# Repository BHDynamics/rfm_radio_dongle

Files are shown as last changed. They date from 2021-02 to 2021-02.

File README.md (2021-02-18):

# DynaLoRa USB Radio Dongle
DynaLoRa USB Radio is a low cost, CircuitPython and Arduino compatible USB radio dongle.

This plaform is equipped with an ATSAMD21 micrcontroller, plus a HopeRF radio module. By default we chose the RFM96W, a LoRa 868 - 915 MHz module based on Semtech's SX1276. You can use an RFM95W for 433 MHz, or an RFM69HCW for generic non-LoRa Sub-GHz radios since they are pin compatible.

Hardware in this repository is licenced under **CERN OHL v1.2**.

## Technical details

- ATSAMD21E18 48 MHz Cortex-M0+ processor with 256 KB flash + 32 KB RAM, compatible with CircuitPython and Arduino
- 32 Mbit SPI flash for storing CircuitPython code and libraries
- High performance HopeRF radio module. You can choose between LoRa (RFM96W, RFM95W) or regular Sub-GHz (RFM69HCW).
- User-controllable WS2812B addressable RGB LED
- Regular user LED
- 3V3 @ 1A power through a DC/DC buck regulator from USB
- MicroSD Card slot
- GPIO header exposing SWD interface, a full SERCOM (enabling external SPI/I2C/UART peripherals) and a DAC for prototyping
- This version comes with an USB-A plug. It should be easy enough to modify the design to offer other options (such as USB-C).

## Documentation

Available in our [Wiki](https://github.com/BHDynamics/rfm_radio_dongle/wiki).

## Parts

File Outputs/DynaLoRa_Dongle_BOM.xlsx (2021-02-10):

Reference(s) | Qty | Part Number | Value | Comments
C1, C2 | 2 |  | 10nF | 10 nF 0402
C3, C4 | 2 |  | 100nF | 100 nF 0402
C5 | 1 |  | 1uF | 1 uF 0603
C6, C9, C10 | 3 |  | 22uF | 22 uF 0603 X5R or X7R
D1 | 1 | WS2812B-MINI | WS2812B-MINI | Addressable LED RGB
D2 | 1 |  | LED_Small | 0805 Red LED
D3 | 1 |  | LED_Small | 0805 Blue LED
J1 | 1 | DO NOT PLACE | Conn_01x07 | Pin header 1x07 2.54 mm SMD horizontal
J2 | 1 | U217-041N-4BV81 | USB_A | USB-A 2.0 Plug
J3 | 1 | PCB.RPSMAFRA.HT* | Conn_Coaxial | SMA THT female connector with pin.
J4 | 1 | TF-102-18 | Micro_SD_Card | MicroSD card slot
L2 | 1 | L1210R2R2MDWIT | 2.2uH | 1210 2.2uH 2A Inductor
R1, R2, R6, R7 | 4 |  | 100k | 100k 0402 1%
R3, R4, R5 | 3 |  | 510R | 510 ohm 0402 1%
R8 | 1 |  | 22k | 22.1k 0402 1%
SW1, SW2 | 2 | B3U-3000P | SW_Push | SMD push button
U1 | 1 | GD25Q32CNIGR | GD25Q32 | 32 Mbit QSPI flash memory
U2 | 1 | ATSAMD21E18A-AUT | ATSAMD21E18A | Cortex-M0 MCU
U3 | 1 | RFM95W | RFM9X | 868-915 MHz LoRa Radio module
U4 | 1 | SY8088AAC | SY8088 | DC/DC Buck converter

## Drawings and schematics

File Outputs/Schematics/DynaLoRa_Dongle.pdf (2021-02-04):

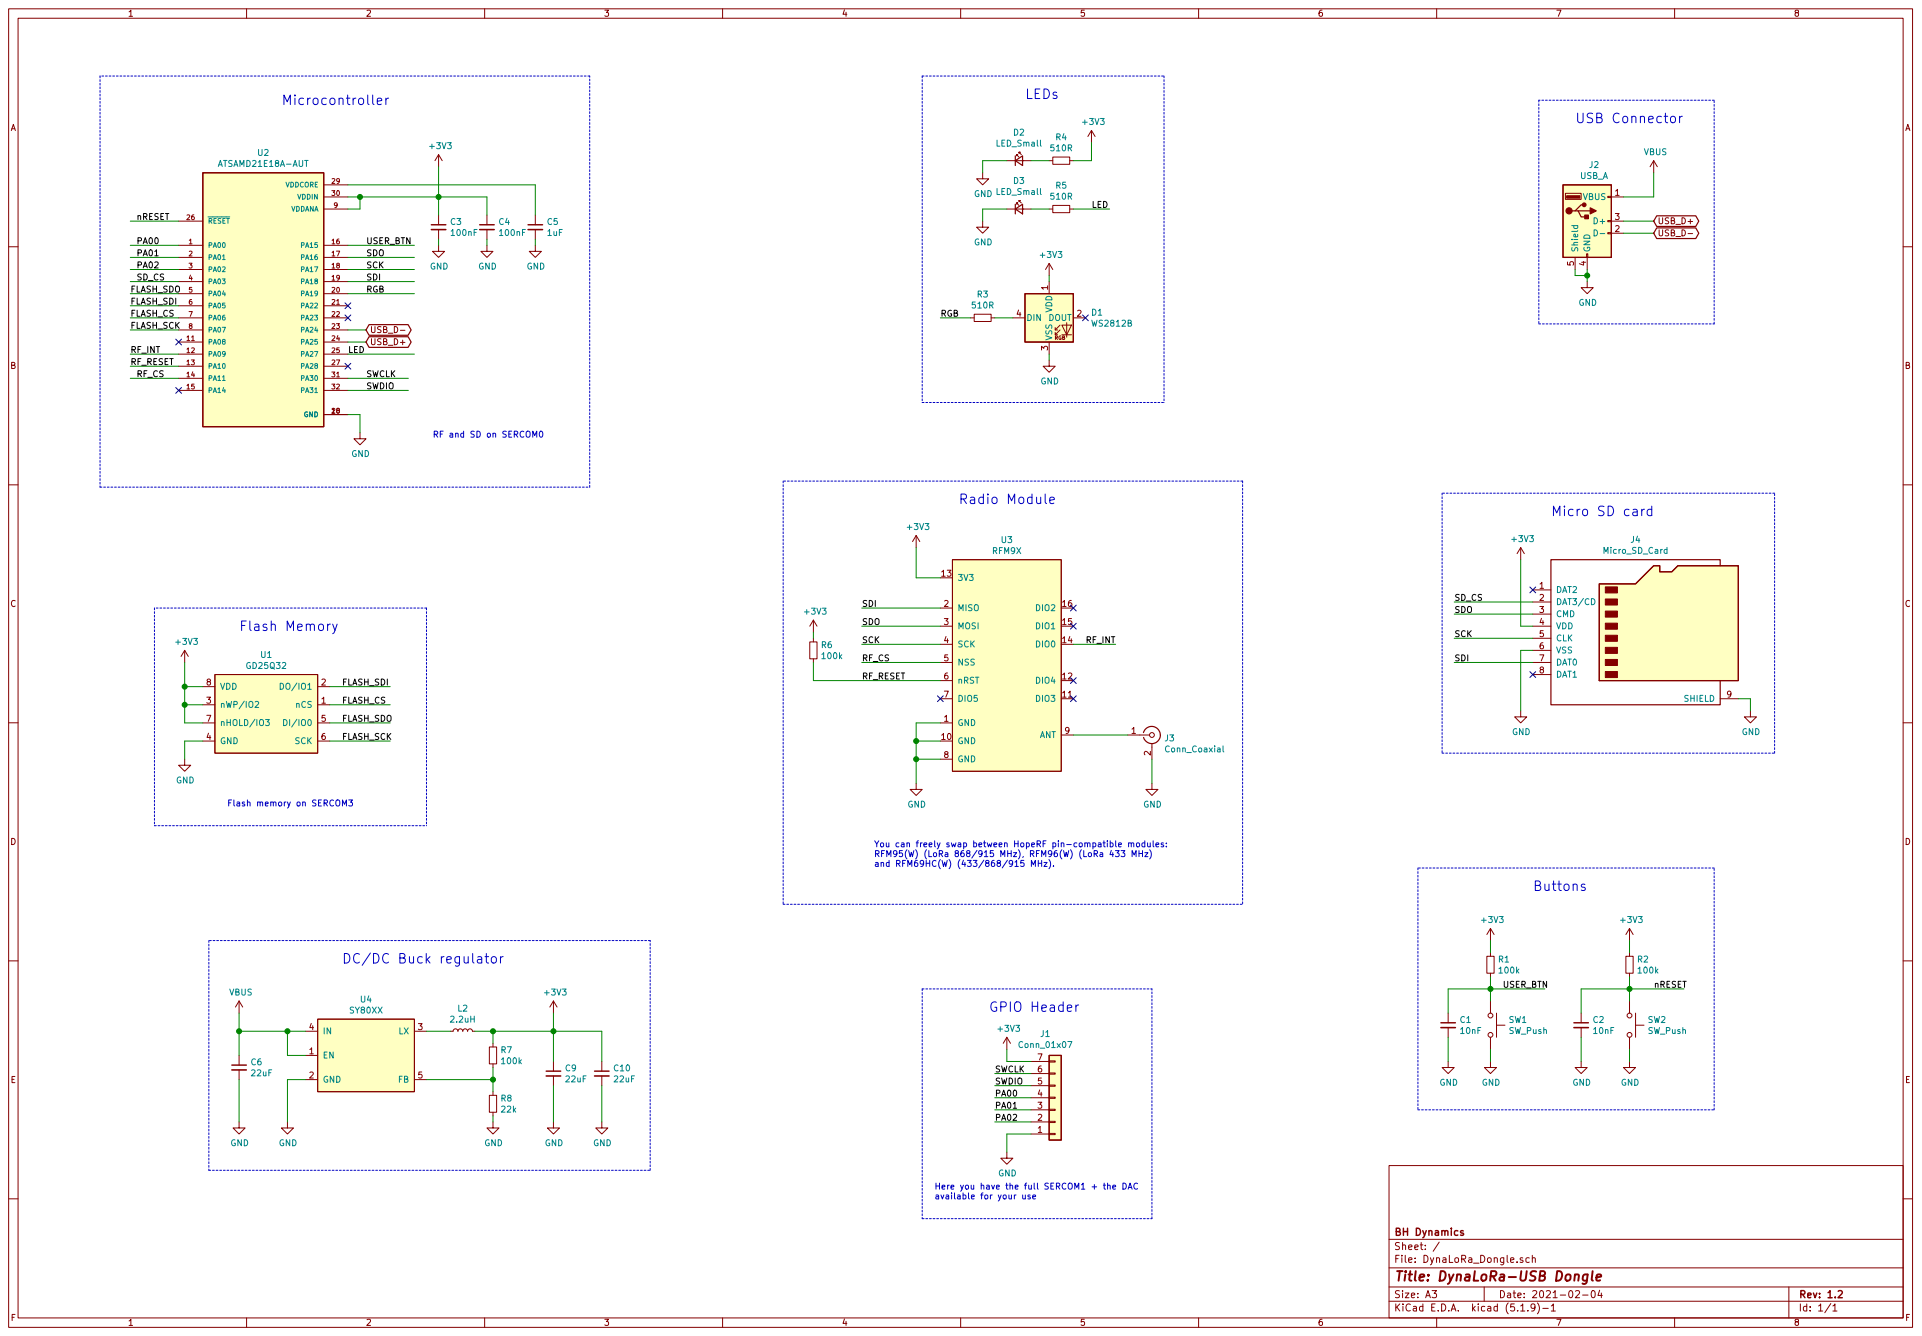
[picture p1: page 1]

You can freely swap between HopeRF pin-compatible modules:
RFM95(W) (LoRa 868/915 MHz), RFM96(W) (LoRa 433 MHz)
and RFM69HC(W) (433/868/915 MHz).

DC/DC Buck regulator

Here you have the full SERCOM1 + the DAC
available for your use

File: DynaLoRa_Dongle.sch Sheet: / BH Dynamics

Id: 1/1 Title: DynaLoRa-USB Dongle

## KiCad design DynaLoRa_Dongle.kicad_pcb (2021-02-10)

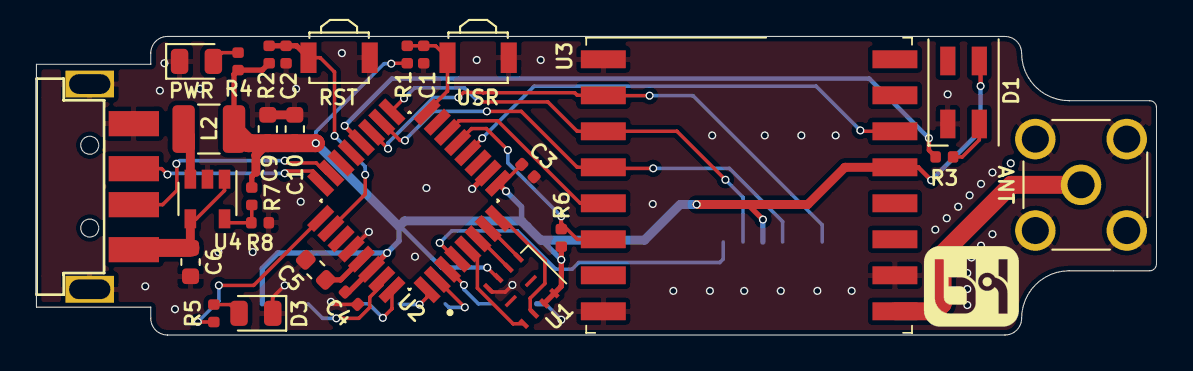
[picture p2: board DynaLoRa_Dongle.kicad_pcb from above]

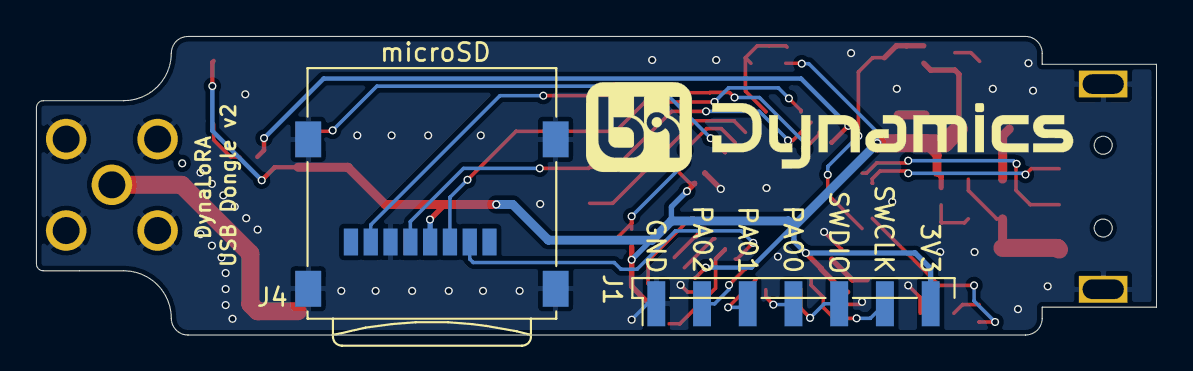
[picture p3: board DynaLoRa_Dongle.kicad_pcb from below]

Board: 2 copper layers, 62.2 x 16.6 mm, 30 parts (2 on the bottom side), 32 nets.

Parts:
C1, C2: 10nF; C_0402_1005Metric
C3, C4: 100nF; C_0402_1005Metric
C5: 1uF; C_0603_1608Metric
C6, C9, C10: 22uF; C_0603_1608Metric
D1: WS2812B; LED_SK6812MINI_PLCC4_3.5x3.5mm_P1.75mm
D2, D3: LED_Small; LED_0805_2012Metric
J1: Conn_01x07; PinHeader_1x07_P2.54mm_Vertical_SMD_Pin1Left
J2: USB_A; C46394
J3: Conn_Coaxial; SMA_Molex_73251-2200_Horizontal
J4: Micro_SD_Card; TF-102-18
L2: 2.2uH; L_1210_3225Metric
R1, R2, R6, R7: 100k; R_0402_1005Metric
R3, R4, R5: 510R; R_0402_1005Metric
R8: 22k; R_0402_1005Metric
SW1, SW2: SW_Push; SW_SPST_B3U-3000P
U1: GD25Q32; WSON-8-1EP_3x4mm_P0.8mm
U2: ATSAMD21E18A-AUT; QFP80P900X900X120-32N
U3: RFM9X; HOPERF_RFM69HW
U4: SY80XX; SOT-23-5

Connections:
+3V3: C3.1, C4.1, C9.1, C10.1, D1.1, J1.7, J4.4, L2.2, R1.1, R2.1, R4.1, R6.1, R7.1, U1.3, U1.7, U1.8, U2.9, U2.30, U3.13
/FLASH_CS: U1.1, U2.7
/FLASH_SCK: U1.6, U2.8
/FLASH_SDI: U1.2, U2.6
/FLASH_SDO: U1.5, U2.5
/LED: R5.1, U2.25
/PA00: J1.4, U2.1
/PA01: J1.3, U2.2
/PA02: J1.2, U2.3
/RF_CS: U2.14, U3.5
/RF_INT: U2.12, U3.14
/RF_RESET: R6.2, U2.13, U3.6
/RGB: R3.2, U2.20
/SCK: J4.5, U2.18, U3.4
/SDI: J4.7, U2.19, U3.2
/SDO: J4.3, U2.17, U3.3
/SD_CS: J4.2, U2.4
/SWCLK: J1.6, U2.31
/SWDIO: J1.5, U2.32
/USER_BTN: C1.1, R1.2, SW1.1, U2.16
/nRESET: C2.1, R2.2, SW2.1, U2.26
GND: C1.2, C2.2, C3.2, C4.2, C5.2, C6.2, C9.2, C10.2, D1.3, D2.1, D3.1, J1.1, J2.4, J2.5, J3.2, J4.6, J4.9, R8.2, SW1.2, SW2.2, U1.4, U2.10, U2.28, U3.1, U3.8, U3.10, U4.2
unnamed: C5.1, U2.29
unnamed: D1.4, R3.1
unnamed: D2.2, R4.2
unnamed: D3.2, R5.2
unnamed: J3.1, U3.9
unnamed: L2.1, U4.3
unnamed: R7.2, R8.1, U4.5
USB_D+: J2.3, U2.24
USB_D-: J2.2, U2.23
VBUS: C6.1, J2.1, U4.1, U4.4

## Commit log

2020-11-25 Initial commit, empty project
    [Radio_Dongle.kicad_pcb, Radio_Dongle.sch]
2020-11-25 Schematics WIP, SPI missing
    [Radio_Dongle.sch]
2020-12-01 v1.1 - Add GPIO header + SD Card
    [LoRa_Dongle-B_Cu.gbr, LoRa_Dongle-B_Fab.gbr, LoRa_Dongle-B_Mask.gbr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]
2020-12-10 Version 1.1 - Thin
    [LoRa_Dongle-B_Cu.gbr, LoRa_Dongle-B_Fab.gbr, LoRa_Dongle-B_Mask.gbr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]
2021-02-04 v1.2, fix SD card GND and button silkscreen. RC
    [DynaLoRa_Dongle-B_Cu.gbr, DynaLoRa_Dongle-B_Fab.gbr, DynaLoRa_Dongle-B_Mask.gbr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]
2021-02-10 Update outputs folder
    [DynaLoRa_Dongle-B_Cu.gbr, DynaLoRa_Dongle-B_Fab.gbr, DynaLoRa_Dongle-B_Mask.gbr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]
